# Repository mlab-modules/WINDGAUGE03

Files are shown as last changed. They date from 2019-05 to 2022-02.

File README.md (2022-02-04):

<!--- PrjInfo ---> <!--- Please remove this line after manually editing --->
<!--- 00a56be08b96043df9e37d6aff7b6990 --->
<!--- Created:2019-04-25 18:04:07.487886: ---> 
<!--- Author:: ---> 
<!--- AuthorEmail:: ---> 
<!--- Tags:: ---> 
<!--- Ust:: ---> 
<!--- Label --->
<!--- ELabel ---> 
<!--- Name:WINDGAUGE03A: --->
# WINDGAUGE03A
<!--- LongName --->
## Venturi tube based anemometer
<!--- ELongName ---> 

<!--- Lead --->
High-endurance venturi anemometer with minimum moving parts. Automatic estimation of direction to magnetic nort. 
<!--- ELead ---> 

<!--- Description --->

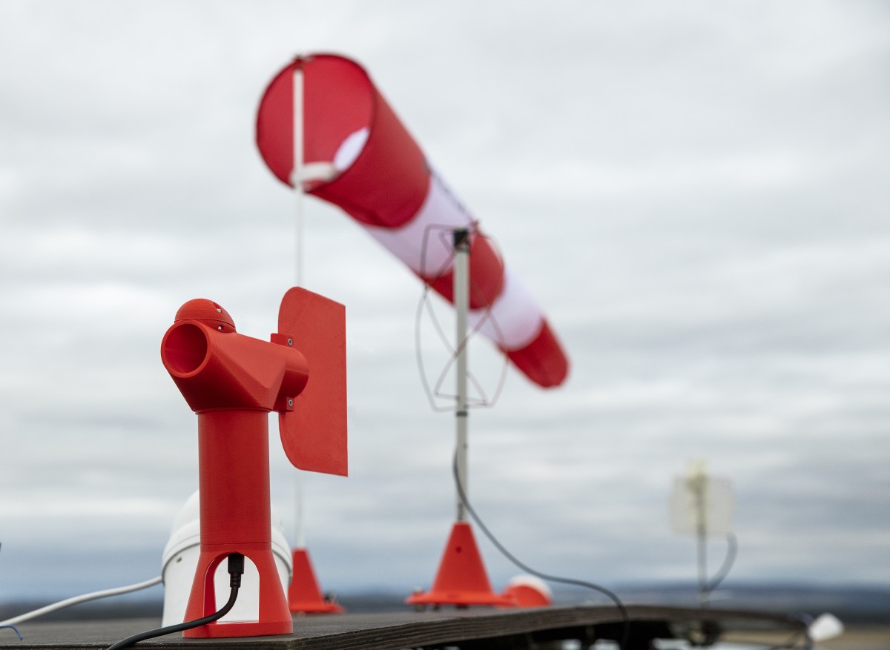
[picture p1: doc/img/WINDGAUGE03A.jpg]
WINDGAUGE03A
 

### Advantages
  * Minimised number of moving parts results in increased durability
  * Venturi effect allows accurate measurement in wide range of speeds is especially sensitive for common low airspeeds  

### Function principle

The measuring tube consist an orifice, which increases airflow in the tube. The different speeds generates differentiall preassure, which is measured by electronic differential pressure sensor.  The same principle was used in beginnig of [aircraft airspeed measurement](https://ntrs.nasa.gov/citations/19930091190). It is advantageous due to better sensitivity at lows speeds compared to [pitot-static](https://en.wikipedia.org/wiki/Pitot_tube) tube. 

The anemometer consists the IMU sensor ICM-20948 which contains magnetometer, gyroscopes and accelerometers. The IMU allows sophisticated data aquisition for failure detection and gust wind analysis. 

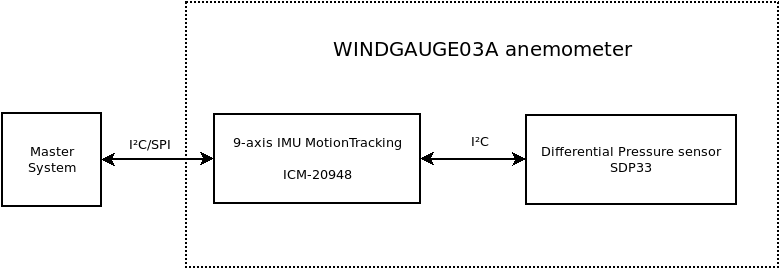
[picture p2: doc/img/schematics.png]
WINDGAUGE03A schematics
 

### Main parameters
  
  * Absolute azimuth accuracy 1° (to magnetic north)
  * Wind speed measurement range 0-120 km/h
  * Maximum mechanically safe wind speed 150 km/h
  * Communication interfaces: 
    * USB
    * I²C
  * Operational temperature range -20/+45 °C
  * Maximum hail diameter 0.5 cm 

### Software installation 

The anemometer uses [pymlab](https://github.com/MLAB-project/pymlab) software toolkit to interface with a station computer. The toolkit also contains an [example](https://github.com/MLAB-project/pymlab/blob/master/examples/windgauge03a_example.py) which allows basic calibration and data recording of anemometer data. 

#### Usage 

##### Calibration 

Anemometer should be calibrated before the first use. That ensures, calibration of magnetometer parameters. To correctly determine the wind direction by internal magnetometer. 

    python3 serial_logger.py 68  15

<!--- EDescription --->
<!--- Content --->
<!--- EContent --->
<sub><sup> Generated with [MLABweb](https://github.com/MLAB-project/MLABweb). (2019-04-25)</sup></sub>

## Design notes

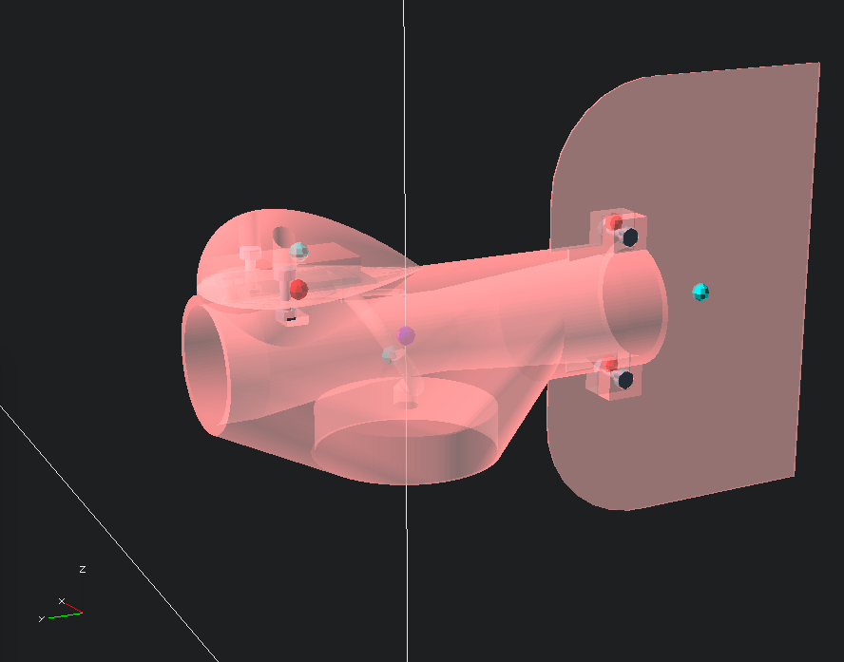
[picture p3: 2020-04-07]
doc/img/rotorpart_balancing.png

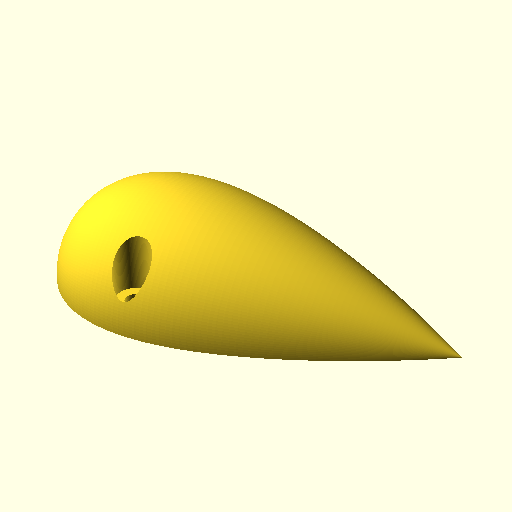
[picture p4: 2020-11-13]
doc/img/WINDGAUGE_R04.png

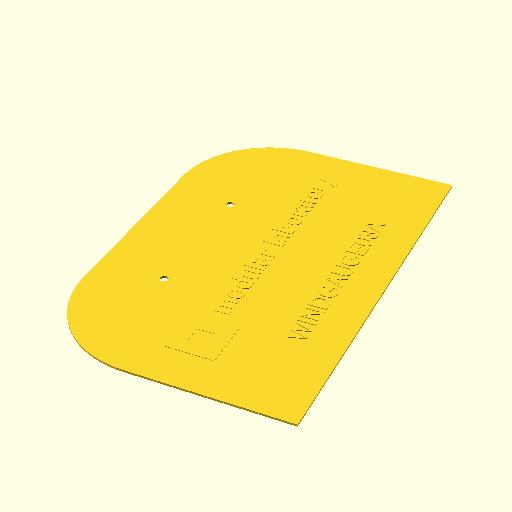
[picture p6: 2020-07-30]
doc/img/WINDGAUGE_R05.png

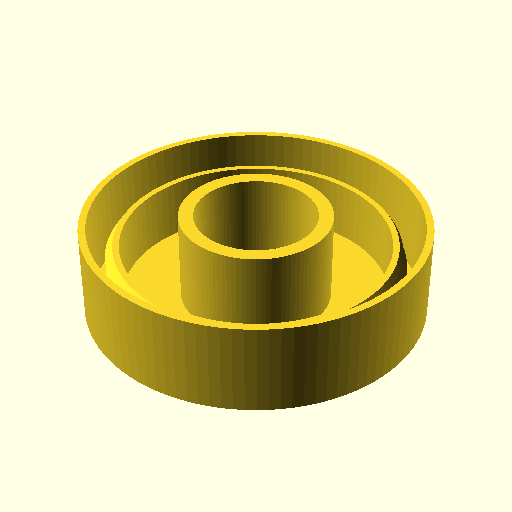
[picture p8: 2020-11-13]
doc/img/WINDGAUGE_S01.png

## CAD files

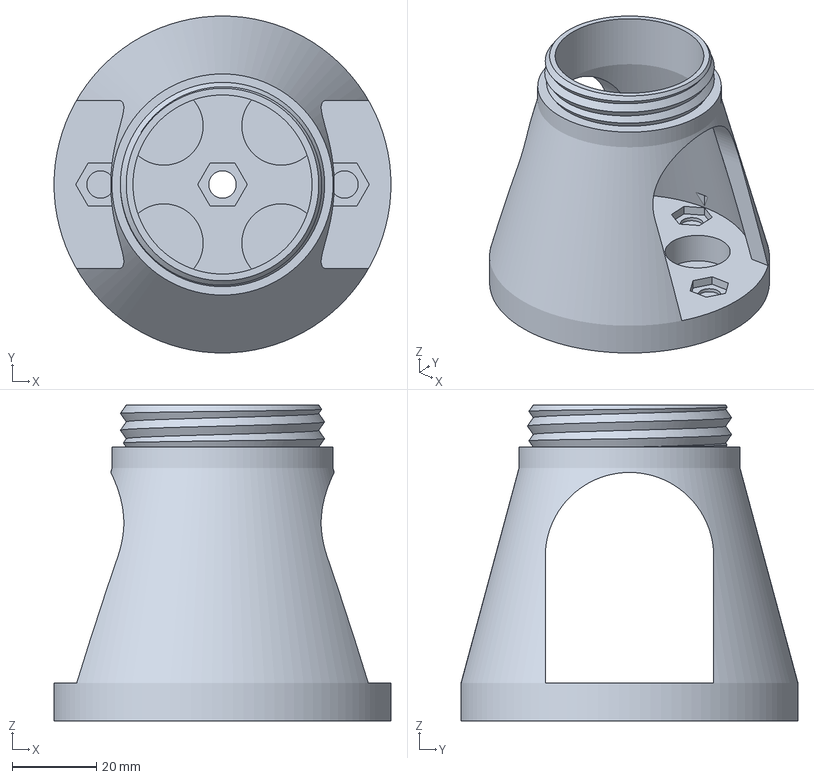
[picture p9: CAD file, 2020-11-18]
amf/WINDGAUGE_D02.amf
80.0 x 80.0 x 75.0 mm

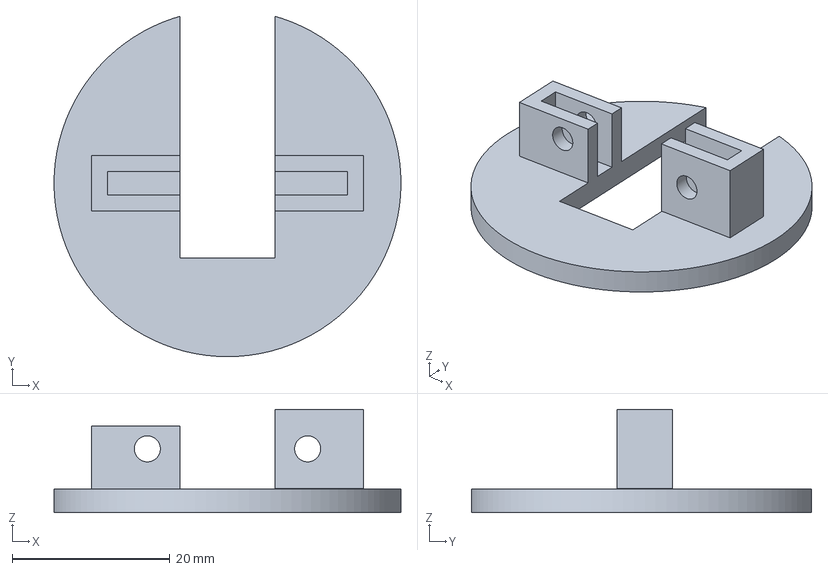
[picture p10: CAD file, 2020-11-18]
amf/WINDGAUGE_S04_USBI2C01A.amf
44.0 x 43.2 x 13.1 mm

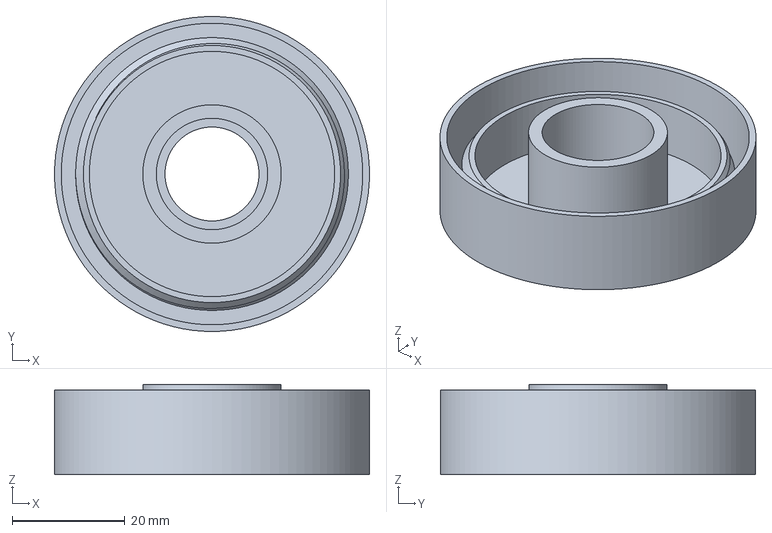
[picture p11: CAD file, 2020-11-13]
amf/WINDGAUGE_S01.amf
56.0 x 56.0 x 16.0 mm

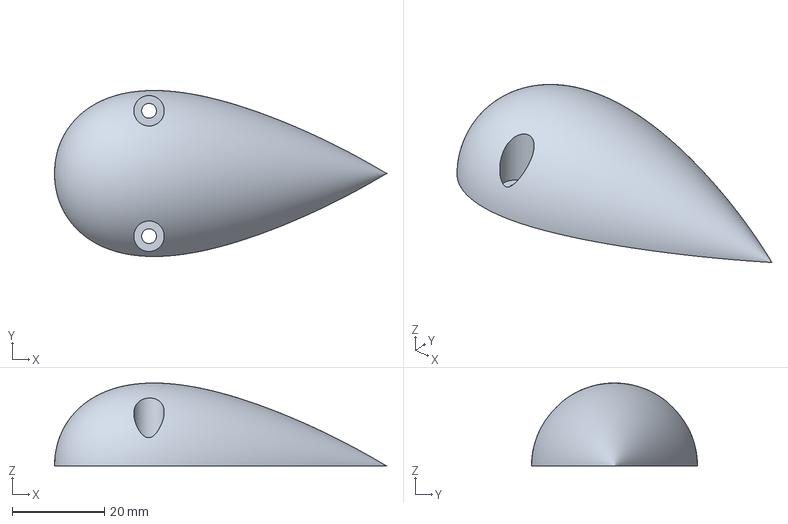
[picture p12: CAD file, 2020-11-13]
amf/WINDGAUGE_R04.amf
72.0 x 36.0 x 18.0 mm

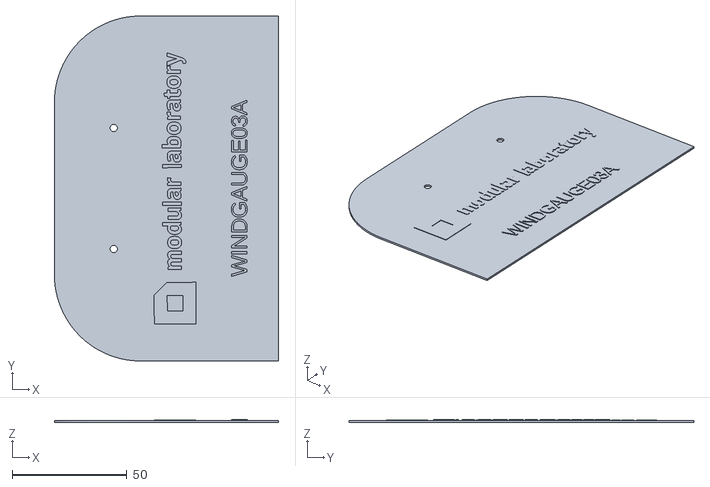
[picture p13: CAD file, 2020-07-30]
doc/stl/WINDGAUGE_R05.stl
97.5 x 150.0 x 1.10

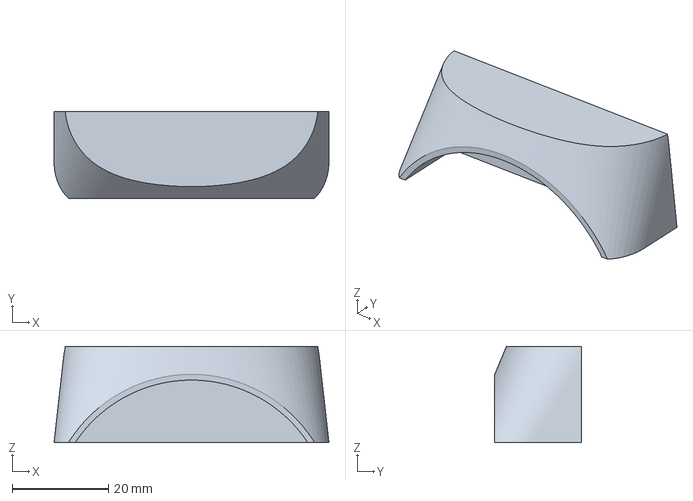
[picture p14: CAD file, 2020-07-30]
amf/WINDGAUGE_R03_test.amf
57.2 x 18.0 x 20.0 mm

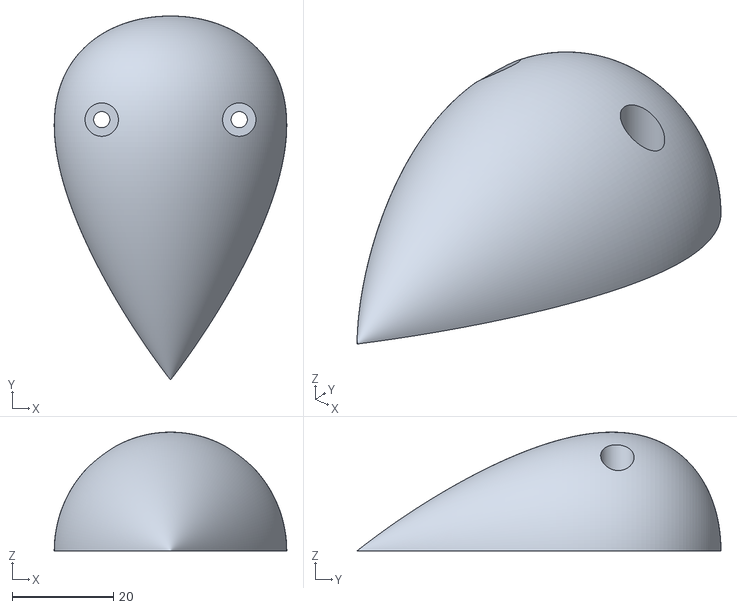
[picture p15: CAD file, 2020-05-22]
doc/stl/WINDGAUGE_R04.stl
46.0 x 72.0 x 23.5

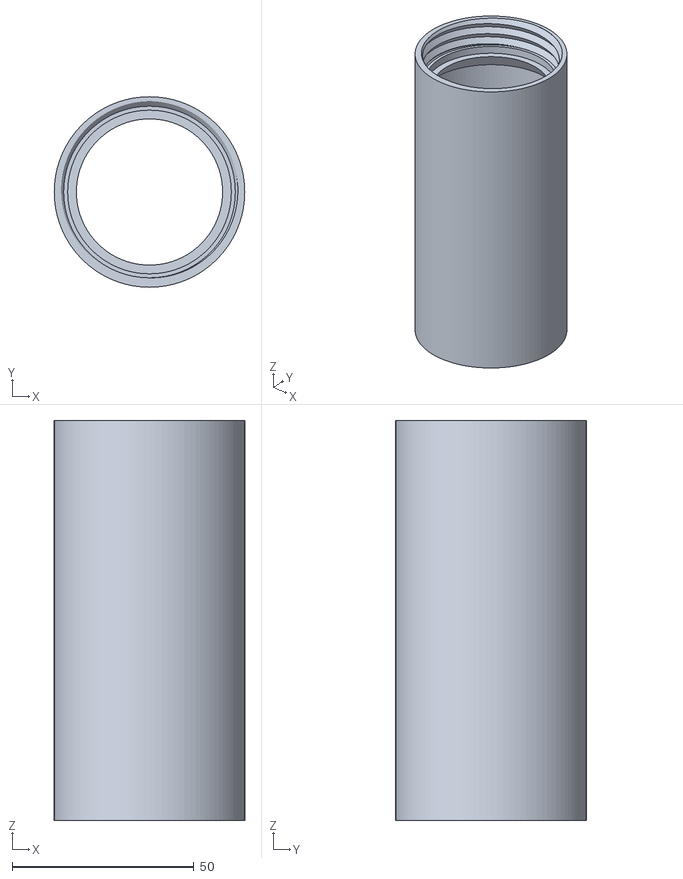
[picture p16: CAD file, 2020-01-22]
doc/stl/WINDGAUGE_S02.stl
52.4 x 52.4 x 110.0

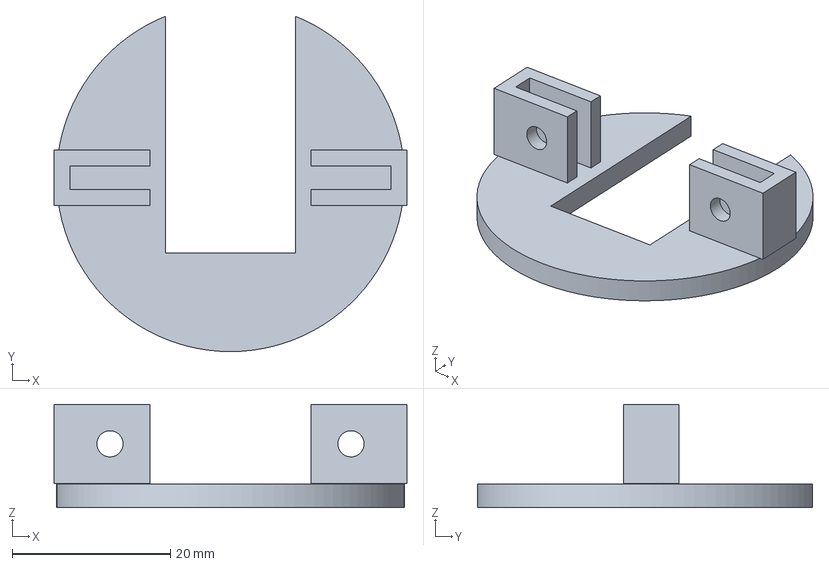
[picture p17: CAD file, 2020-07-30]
amf/WINDGAUGE_S04.amf
44.6 x 42.4 x 13.1 mm

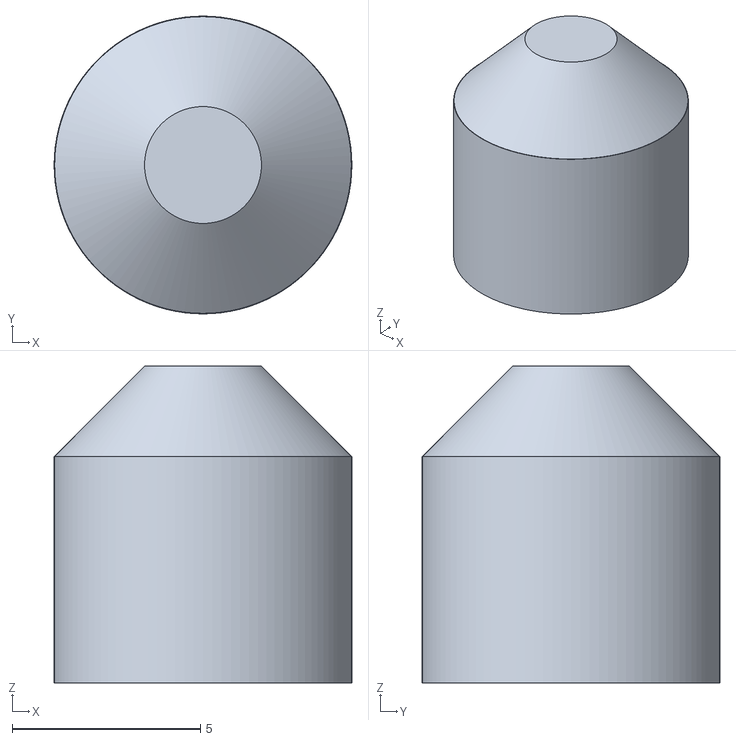
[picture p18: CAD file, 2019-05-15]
doc/stl/WINDGAUGE_R06.stl
7.90 x 7.90 x 8.41

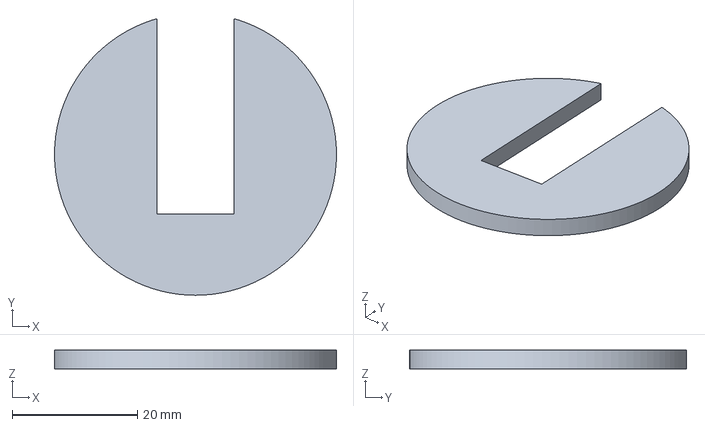
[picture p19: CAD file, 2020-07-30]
amf/WINDGAUGE_S03.amf
45.0 x 44.1 x 3.00 mm

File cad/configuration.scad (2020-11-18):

//$fn=40; // model faces resolution.

//COMMON PARAMETERS
global_clearance = 0.5; // additional space where needed due to printer precision
layer_thickness = 0.3; // layer which is going to be removed after printing
//M3 x 12 Bolt
M3_nut_diameter = 6.6;
M3_nut_height = 2.7;
M3_bolt_diameter = 3.2;
M3_bolt_head_height = 3;
M3_bolt_length = 12;
//M5 Bolt
M5_bolt_diameter = 5.5;
M5_nut_height = 4.5;
M5_nut_diameter = 9.4;
//M6 Bolt
M6_bolt_diameter = 6.5;
M6_nut_height = 4.9;
M6_nut_diameter = 11.8;


//----------------------------------------------------------------
//----------------------------------------------------------------
//WINDGAUGE02A_S02 - Parametry pro hlavni valec anemometru
S01_hloubka_zavitu=4;
S01_vyska=110; //80
S01_prumer_vnitrni=50;
S01_sila_materialu=1.2;
S01_vyska_horni_zavit=10;
S01_vyska_spodniho_zavitu=10;
S01_sila_drzaku_RJ11=3; //vyška drážky
S01_hrana_A_RJ11=12.3;
S01_hrana_B_RJ11=19;
S01_tolerance_zavit=1.5;

//Rozměry ložiska se závity
//LO_spodni_prumer=22;
LO_spodni_prumer=16.7; //bez krytu
slip_ring_mount_height=1.5;
slip_ring_mount_diameter=16.7;
LO_horni_prumer=7.7;
//LO_vyska_spodni_doraz=5;
//LO_vyska_horni_doraz=9;
//LO_vyska_dorazu=0;
slip_ring_body_height = 16;
slip_ring_body_diameter = 19.8;



//Obecné parametry
prumer_osicky=5.1;



//Parametry loziska
lozisko_prumer_vnitrni=4.9;
lozisko_prumer_vnejsi=16.1;
lozisko_vyska=5;
lozisko_prekryv=1.5;

//Parametry magnetu
magnet_prumer=6.3;
magnet_vyska=5;
magnet_zapusteni=2;
magnet_tolerance_prumeru=0.2;

//Parametry sroubu
prumer_sroubu=3.4;
prumer_hlavy_sroubu=8.2;
vyska_hlavy_sroubu=4.3;
vyska_matky=3;
sirka_matky=6.7;

sirka_matky_tol=0.175;
prumer_orechu=10;

//WINDGAUGE02A_R01 //pro lopatku
L01_hrana_drzaku_a=10;
L01_hrana_drzaku_b=3;
L01_delka_uchytu=19;
L01_prumer_lopatky=40;
L01_sila_materialu_lopatky=0.9;

//WINDGAUGE02A_D02 Anemometer holder
//   | |   Top ring with Screw-thread
//  /   \  Body
// |_____| Base
D02_magnet_base_height = 4.5 + 1.5*global_clearance; // HS-13 M5 magnet height without bolt
D02_magnet_diameter = 16.1 + global_clearance; // HS-13 M5 magnet diameter
D02_flat_magnet_diameter = 18.1 + global_clearance; // HS-13 M5 magnet diameter
D02_wall_thickness = 5; // body wall thickness
D02_connector_spacing = 40; // main body cut-through for connectors
D02_base_diameter = 80; // diameter of holder base
D02_base_height = max(M6_nut_height + 1.5,
                      D02_magnet_base_height + M5_nut_height/2 + 1.5); // height of holder base
D02_body_height = 60 - D02_base_height; // height of body between base and top ring
D02_screw_diameter = S01_prumer_vnitrni - S01_tolerance_zavit; // scew-thread diameter based on stand S01
D02_thread_height = S01_vyska_spodniho_zavitu; // screw-thread height based on stand S01
D02_top_ring_inner_diameter = D02_screw_diameter - 6; // inner diameter of top ring
D02_top_ring_outer_diameter = D02_screw_diameter + 4; // outer diameter of top ring
D02_top_ring_height = D02_thread_height + 5; // height of top ring
D02_total_height = D02_base_height + D02_body_height + D02_top_ring_height; // total height of anemometer holder
// Following parameters are obsolete, maintained only for compatibility.
D01_material_pod_zavitem = D02_top_ring_height - D02_thread_height;
D01_material_za_zavitem = D02_screw_diameter - D02_top_ring_inner_diameter;
D01_material_pred_zavitem = D02_top_ring_outer_diameter - D02_screw_diameter;
D01_polomer_zakladny = D02_base_diameter/2;
D01_sila_setny_spodniho_drzaku=D02_wall_thickness;
D01_vyska_spodni_casti_drzaku = D02_body_height + D02_base_height;
D01_sirka_otvoru_pro_konektor = D02_connector_spacing;
D01_ucyhtna_matice_material_nad = D02_base_height - M6_nut_height;
D01_uchytna_matice_vyska = M6_nut_height;
D01_uchytna_matice_sirka = M6_nut_diameter;
D01_uchytny_sroub_prumer = M6_bolt_diameter;

// Following parameters are actually used in D01 model.
//WINDGAUGE02A_D02 //uchyt na sloup
D02_sila_materialu=6;
D02_vyska_uchytky=40;
D02_prumer_obruby=27; // 3/4 trubka
D02_delka_celeho_uchytu=60;
D02_dotahova_vzdalenost=1.5;
D02_prumer_uchytneho_sroubu=4.2;
D02_sirka_matky=9.1; //pro M4
D02_vyska_matky=3;


//WINDGAUGE02A_R01 //rotor s prekritim statoru
R01_vyska_prekryti_statoru=10;
R01_sila_materialu_pro_prekriti=1.3;
R01_mezera_mezi_statorem_rotorem=3;

//WINDGAUGE02A_R03 //drzak magnetu
R05_sirka_matky=10;



R03_prumer_zavitu=40;
R04_zavit_vyska=5;
R02_zavit_vyska=10;
R01_zavit_vyska=5;
R03_mezera_mezi_statorem_rotorem=3;

R02_delka_kridla=45;
R02_vzdalenost_der=25;

R02_delka_vyrovnnavaci_tyce=35;
R02_hrana_drzaku=14;
R02_sila_materialu_pod_tyci=5;
R02_sila_materialu_kridla=1.2;
R02_sila_materialu_kridla_tolerance=0.3;

R05_vyska_kridla=100;
R05_delka_kridla=100;


//S04
I2CDIFF01A_sirka_kon=16.5; //sirka konektoru
I2CDIFF01A_vyska_kon=13.5; //vyska konektoru
I2CDIFF01A_sirka_mod_otvory=4; //kolik modul zabira der
I2CDIFF01A_vyska_PCB=2; //vyska mezi albase a konektorem
S04_sila_materialu=2;

//S04_USBI2C01A
USBI2C01A_sirka_kon=12; //sirka konektoru
USBI2C01A_vyska_kon=11; //vyska konektoru
USBI2C01A_sirka_mod_otvory=3; //kolik modul zabira der
USBI2C01A_vyska_PCB=2; //vyska mezi albase a konektorem


//WINDGAUGE03A_R03 // Venturi tube
R03_wide_D = 36; // Venturi wide tube inner diameter
R03_narrow_D = R03_wide_D/1.7; // Venturi narrow tube inner diameter
R03_global_clearance = global_clearance; // additional space where needed due to printer precision
R03_PCB_top_rim = 5.5; // vertical distance from top of tube to top of PCB
R03_PCB_height = 41; // height of PCB casing - if changed check casing
R03_PCB_width = 14; // width of PCB casing - if changed check casing
R03_PCB_depth = 3.7; // depth of PCB casing - if changed check casing
R03_PCB_connector_overlay = 2.5; // additional depth of PCB casing on connectors side - if changed check casing
R03_PCB_elevation = 2; // additional elevation of PCB for waterproofing
R03_air_tube_diameter = 2; // air tubes diameter
R03_sensor_housing_offset = 15;  // distance from venturi tube height to sensor housing drop
R03_sensor_offset = 2.2;  // SDP33 distance from PCB border to sensor
R03_sensor_pitch = 4.3;  // SDP33 distance between sensors
R03_sensor_diameter = 3.5;  // SDP33 sensor diameter
R03_sensor_depth = 2.5;  // SDP33 sensor depth
R03_slip_ring_offset = 0; // slip-ring offset from tube center
R03_venturi_tube_height = 150;  // Venturi tube height (limited by max print size)
R03_wall_thickness = 5; // Venturi tube wall thickness
R03_sealing_ring_thickness = 1.5; // sealing ring size
R03_fin_width = 0.8; // width of vertical stabilizator
R03_fin_length = 80; // length of vertical stabilizator
R03_fin_height = 150; // height of vertical stabilizator
R03_fin_holder_width = M3_bolt_length + M3_nut_height;
R03_fin_holder_height = M3_nut_diameter + 2*R03_wall_thickness;
R03_fin_holder_depth = R03_wide_D/2 + R03_fin_holder_height;
R03_balance_shelf_width = 20; // width of shelf for balance weights
R03_balance_shelf_height = 10; // height of shelf for balance weights

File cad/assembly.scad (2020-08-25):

include <configuration.scad>

parts_separation = 0;

//D02 - Anemometer holder
D02_z0 = 0;
translate([0, 0, D02_z0])
    rotate([0, 0, 0])
        import("../doc/stl/WINDGAUGE_D02.stl");

//S02 - Extender
S02_z0 = D02_z0 + D02_total_height - D02_thread_height + parts_separation;
translate([0, 0, S02_z0])
    rotate([0, 0, 0])
        import("../doc/stl/WINDGAUGE_S02.stl");

//S01 - Bearings holder
S01_z0 = S02_z0 + S01_vyska + parts_separation;
translate([0, 0, S01_z0])
    rotate([180, 0, 0])
        import("../doc/stl/WINDGAUGE_S01.stl");

//R03 - Venturi tube
R03_y0 = -2*R03_venturi_tube_height + R03_slip_ring_offset + 6*R03_wide_D;
R03_z0 = S01_z0 + R03_wide_D/2 + 5 + parts_separation;
%translate([0, R03_y0, R03_z0])
    rotate([270, 180, 0]){
        import("../doc/stl/WINDGAUGE_R03.stl");
    }
echo("WINDGAUGE_R03 coordinates are: [0, ", R03_y0, R03_z0, "]");

//R04 - PCB lid
R04_x0 = -R03_wide_D/2;
R04_y0 = R03_venturi_tube_height + R03_y0;
R04_z0 = R03_z0 + R03_wide_D/2 + R03_wall_thickness + parts_separation;
%translate([R04_x0, R04_y0, R04_z0 + 0])
    rotate([0, 0, 270])
        import("../amf/WINDGAUGE_R04.amf");
echo("WINDGAUGE_R04 coordinates are: [", R04_x0, R04_y0, R04_z0, "]");


//R05 - Fin
R05_y0 = - 2*R03_venturi_tube_height + R03_slip_ring_offset + 6*R03_wide_D
         - R03_fin_length/2 + R03_fin_holder_height - parts_separation;
R05_z0 = R03_z0;
%translate([0, R05_y0, R05_z0])
    rotate([90, 0, 270])
        import("../amf/WINDGAUGE_R05.amf");
echo("WINDGAUGE_R05 coordinates are: [0, ", R05_y0, R05_z0, "]");

// R03 Front Bolt
FTB_x0 = -M3_bolt_length/2 - M3_nut_height/2;
FTB_y0 = 6.5;
FTB_z0 = R03_z0 - R03_wide_D/2;
color([1, 1, 1])
translate([FTB_x0, FTB_y0, FTB_z0])
    rotate([0, 90, 0])
        import("../amf/BOLT_M3x12.amf");
echo("R03 Front Bolt coordinates are: [",FTB_x0, FTB_y0, FTB_z0,"]");

// R03 Rear Bolt
RTB_x0 = M3_bolt_length/2 + M3_nut_height/2;
RTB_y0 = -6.5;
RTB_z0 = R03_z0 - R03_wide_D/2;
color([1, 1, 1])
translate([RTB_x0, RTB_y0, RTB_z0])
    rotate([0, 90, 180])
        import("../amf/BOLT_M3x12.amf");
echo("R03 Rear Bolt coordinates are: [",RTB_x0, RTB_y0, RTB_z0,"]");

// R04 Left Bolt
LLB_x0 = -R03_PCB_width/2 - M3_nut_diameter;
LLB_y0 = R03_y0 + R03_venturi_tube_height - R03_PCB_height/2;
LLB_z0 = R03_z0 + R03_wide_D/2 - M3_nut_height;
color([1, 1, 1])
translate([LLB_x0, LLB_y0, LLB_z0])
    rotate([0, 0, 90])
        import("../amf/BOLT_M3x12.amf");
echo("R04 Left Bolt coordinates are: [",LLB_x0, LLB_y0, LLB_z0,"]");

// R04 Right Bolt
RLB_x0 = R03_PCB_width/2 + M3_nut_diameter;
RLB_y0 = R03_y0 + R03_venturi_tube_height - R03_PCB_height/2;
RLB_z0 = R03_z0 + R03_wide_D/2 - M3_nut_height;
color([1, 1, 1])
translate([RLB_x0, RLB_y0, RLB_z0])
    rotate([0, 0, 90])
        import("../amf/BOLT_M3x12.amf");
echo("R04 Right Bolt coordinates are: [",RLB_x0, RLB_y0, RLB_z0,"]");

// R05 Upper Bolt
UFB_x0 = -R03_fin_holder_width/2;
UFB_y0 = R03_y0 + R03_fin_holder_height/2;
UFB_z0 = R03_z0 + R03_fin_holder_depth - R03_fin_holder_height/2;
color([1, 1, 1])
translate([UFB_x0, UFB_y0, UFB_z0])
    rotate([0, 90, 0])
        import("../amf/BOLT_M3x12.amf");
echo("R05 Upper Bolt coordinates are: [",UFB_x0, UFB_y0, UFB_z0,"]");

// R05 Lower Bolt
LFB_x0 = -R03_fin_holder_width/2;
LFB_y0 = R03_y0 + R03_fin_holder_height/2;
LFB_z0 = R03_z0 - R03_fin_holder_depth + R03_fin_holder_height/2;
color([1, 1, 1])
translate([LFB_x0, LFB_y0, LFB_z0])
    rotate([0, 90, 0])
        import("../amf/BOLT_M3x12.amf");
echo("R05 Lower Bolt coordinates are: [",LFB_x0, LFB_y0, LFB_z0,"]");

// R03 COG
translate([ -0.4670859999999942 , 6.640354000000002 , 192.837544 ])
    color([0, 1, 1]) sphere(3);
// R04 COG
translate([ 1.0312389999999922 , 36.146445 , 228.245272 ])
    color([0, 1, 1]) sphere(3);
// R05 COG
translate([ -0.4690809999999989 , -101.44978800000001 , 197.63449400000002 ])
    color([0, 1, 1]) sphere(3);
// R03 Front Bolt COG
translate([ 0.7782590000000003 , 6.506229000000005 , 179.993901 ])
    color([1, 0, 0]) sphere(3);
// R03 Rear Bolt COG
translate([ -0.7782590000000003 , -6.506229000000004 , 179.993901 ])
    color([1, 0, 0]) sphere(3);
// R04 Left Bolt COG
translate([ -13.606229000000004 , 45.506099000000006 , 221.42825900000003 ])
    color([1, 0, 0]) sphere(3);
// R04 Right Bolt COG
translate([ 13.593770999999995 , 45.506099000000006 , 221.42825900000003 ])
    color([1, 0, 0]) sphere(3);
// R05 Upper Bolt COG
translate([ 0.7782590000000003 , -75.693771 , 224.293901 ])
    color([1, 0, 0]) sphere(3);
// R05 Lower Bolt COG
translate([ 0.7782590000000003 , -75.693771 , 171.69390099999998 ])
    color([1, 0, 0]) sphere(3);

// WINDGAUGE03_R* COG
translate([ -0.351634926309725 , 0.0062762700057576596 , 195.56655708002305 ])
    color([0, 0, 1]) sphere(3);

// // Desired WINDGAUGE03_R* COG
// translate([ 0, 0, R03_z0 ])
//     color([1, 0, 1]) sphere(3);

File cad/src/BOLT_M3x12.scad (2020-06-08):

include <../configuration.scad>
$fn=200;

cylinder(h = M3_bolt_length, d = M3_bolt_diameter, $fn=50);
cylinder(h = M3_nut_height, d = M3_nut_diameter, $fn=6);
translate([0, 0, M3_bolt_length])
    cylinder(h = M3_bolt_head_height, d = M3_nut_diameter);

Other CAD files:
doc/stl/WINDGAUGE_D02.stl
doc/stl/WINDGAUGE_S04_USBI2C01A.stl
doc/stl/WINDGAUGE_S01.stl
amf/WINDGAUGE_R05.amf
doc/stl/WINDGAUGE_S04.stl
amf/WINDGAUGE_S02.amf
doc/stl/WINDGAUGE_S03.stl
cad/src/WINDGAUGE_R03.scad
amf/BOLT_M3x12.amf
amf/P_WINDGAUGE03A_R03.stl
amf/WINDGAUGE_R03.amf
amf/WINDGAUGE_R03.stl
amf/WINDGAUGE_R06.amf
cad/print_data/P_WINDGAUGE01A_D02.scad
cad/print_data/P_WINDGAUGE01A_R01.scad
cad/print_data/P_WINDGAUGE01A_R03.scad
cad/print_data/P_WINDGAUGE01A_R04.scad
cad/print_data/P_WINDGAUGE01A_S01.scad
cad/print_data/P_WINDGAUGE01A_S02.scad
cad/print_data/P_WINDGAUGE01A_S04.scad
cad/src/WINDGAUGE_D02.scad
cad/src/WINDGAUGE_R04.scad
cad/src/WINDGAUGE_R05.scad
cad/src/WINDGAUGE_R06.scad
cad/src/WINDGAUGE_S01.scad
cad/src/WINDGAUGE_S02.scad
cad/src/WINDGAUGE_S03.scad
cad/src/WINDGAUGE_S04.scad
cad/src/WINDGAUGE_S04_USBI2C01A.scad
doc/stl/BOLT_M3x12.stl

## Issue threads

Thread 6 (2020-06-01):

Uložení servisní délky vodičů

kaklik, 2020-06-01:
Aktuálně navržené řešení uložení vodičů omotáním okolo PCB je prakticky nerealizovatelné.  Problémem je, že nelze udržet vodiče správně umístěné pod víčkem při nasazování víčka.

Nově navržený kanálek pro přivedení vodičů je však dostatečně tlustý na to, aby jím bylo možné protáhnout vodiče i s nakrimpovanými kontakty konektoru. Tím je umožněno zcela nové řešení, že by vodiče byly rovnou správně dlouhé a mohly být přivedeny rovnou do konektoru.
Délka vodičů ale nikdy přesně správná nebude, pouze přibližně. Takže zde je potřeba mít nějakou co největší rezervu. Aktuálně jsem však vyzkoušel, že kanálek je tak široký že v něm vzniká asi 15mm rezerva délky, kterou do něj lze natlačit.  (Možná by bylo možné tuto rezervu zvětšit)

Případně by bylo možná udělat místo pro vodiče vytvořením druhého kanálku z protější strany, než kde vede teď. (Tento kanálek by asi mohl být slepý a přebytečná délka vodiče se do něj natlačí od PCB z vrchní strany)

Vyplývá z toho ale že je zřejmě potřeba obnovit původní menší kapkovitý kryt bez kulatých rohů. Ten byl lepší neboť nespotřebovával tolik materiálu a neměl takový aerodynamický odpor.

JanKott, 2020-06-10:
Zrušil jsem uložení vodiče pod víčko a přidal jsem více místa u vstupu do kanálku pro kabely.
Prosím otestovat, zda je to takto vyhovující.

kaklik, 2020-06-11:
Vodiče lze ukládat do nového tlustého kanálku, který vodiči přivádí.

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

Closed 2020-06-11.

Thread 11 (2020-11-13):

Uchycení modulu USBI2C

kaklik, 2020-11-13:
Do držáku není možné zašroubovat oba šrouby.

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

kaklik, 2020-11-18:
Supr! :)  Commit i obsahuje spojení s tímhle issue! :)

Zkusím to vytisknout a uvidíme, zda to zafungovalo.

kaklik, 2020-11-22:
Vypadá to tak všelijak... Ale účel to zřejmě splňuje..

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

Closed 2020-11-22.

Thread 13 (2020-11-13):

Tolerance trnu pro nasazení na ložisko

kaklik, 2020-11-13:
Jednotlivé typy ložisek mají mírně jiné průměry trnu. V důsledku toho současný průměr otvoru v otočném dílu nepasuje na Adafruit slip ring 22mm.

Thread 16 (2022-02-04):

Návod na sestavení

kaklik, 2022-02-04:
Šrouby pro fixaci osy mají délku 15mm.

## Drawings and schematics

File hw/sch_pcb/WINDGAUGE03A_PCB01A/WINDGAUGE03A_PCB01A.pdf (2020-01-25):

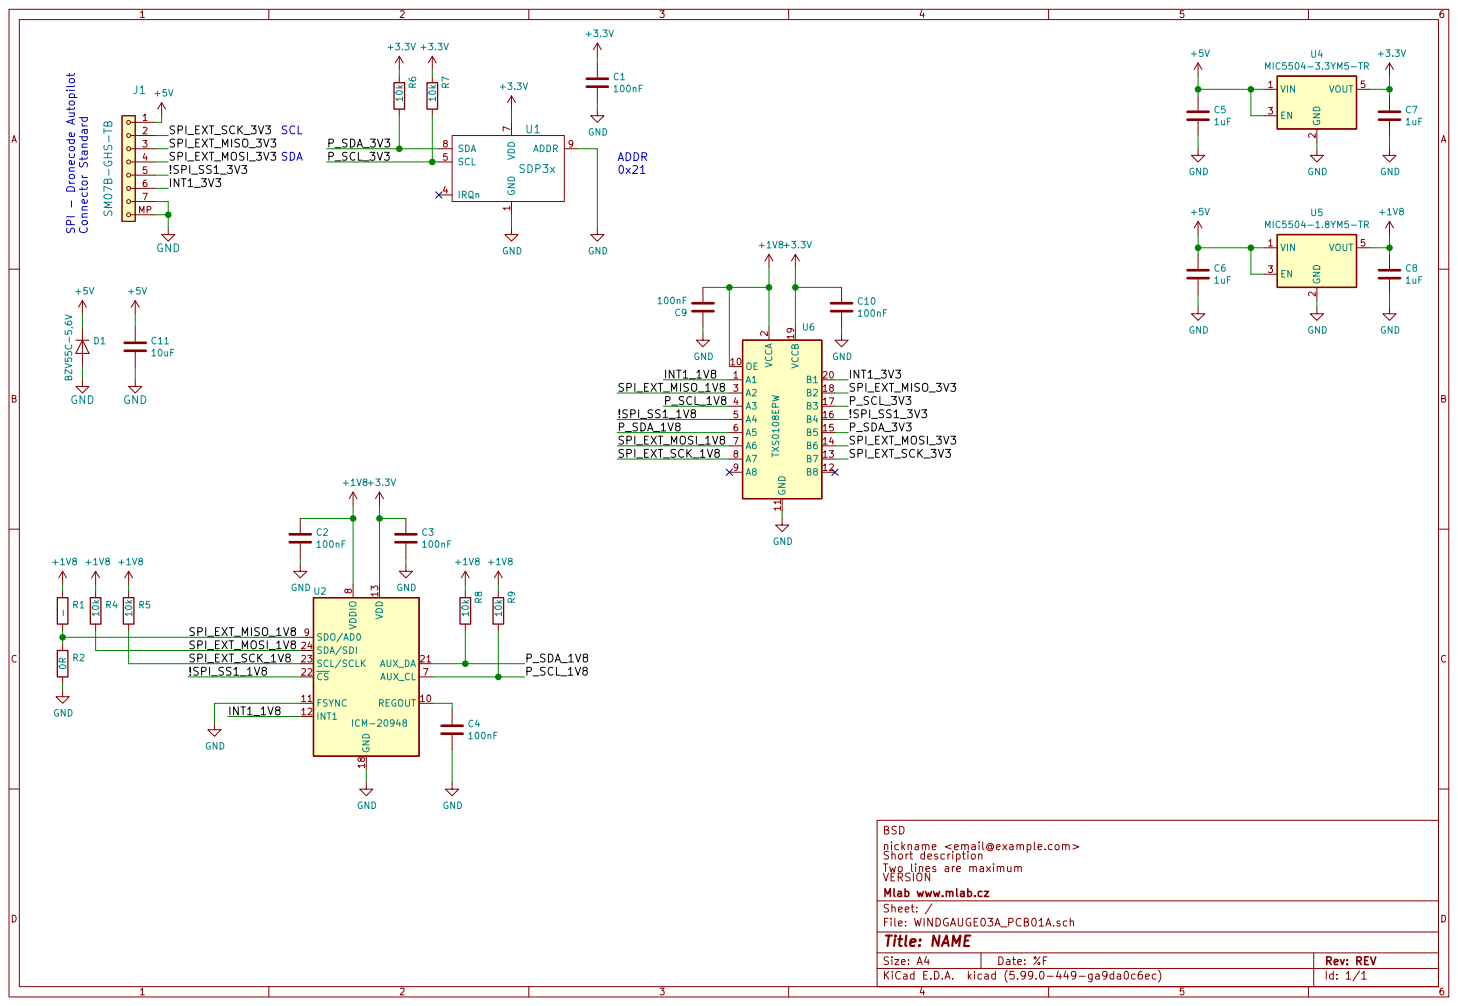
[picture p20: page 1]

+5V SPI - Dronecode Autopilot Connector Standard

7 SDA 8 ADDR 9 U1 SDP3x GND GND

nickname <email@example.com> BSD GND

Short description
File: WINDGAUGE03A_PCB01A.sch Sheet: / Mlab www.mlab.cz VERSION

Two lines are maximum

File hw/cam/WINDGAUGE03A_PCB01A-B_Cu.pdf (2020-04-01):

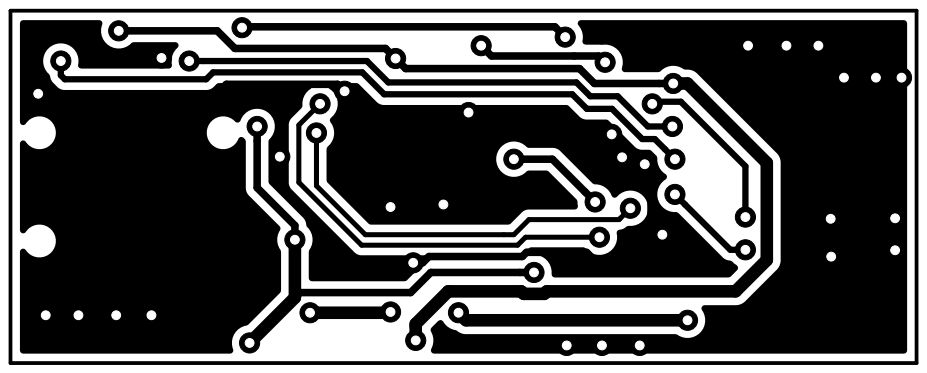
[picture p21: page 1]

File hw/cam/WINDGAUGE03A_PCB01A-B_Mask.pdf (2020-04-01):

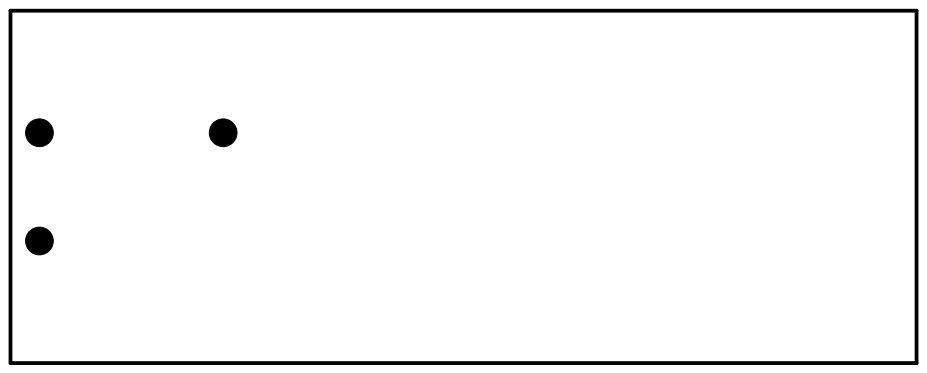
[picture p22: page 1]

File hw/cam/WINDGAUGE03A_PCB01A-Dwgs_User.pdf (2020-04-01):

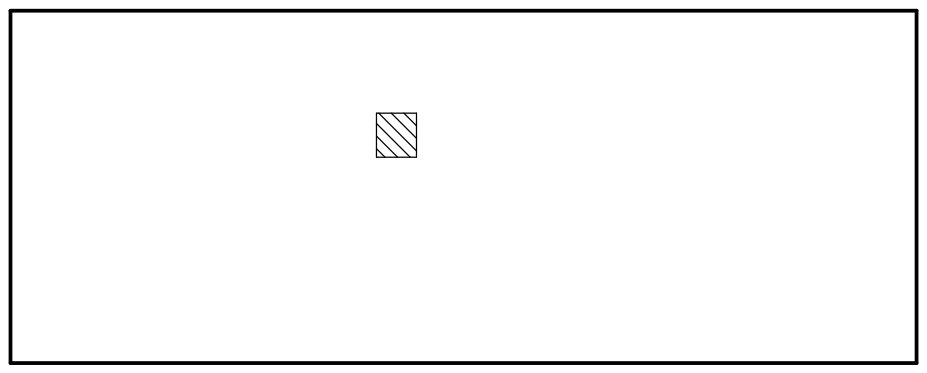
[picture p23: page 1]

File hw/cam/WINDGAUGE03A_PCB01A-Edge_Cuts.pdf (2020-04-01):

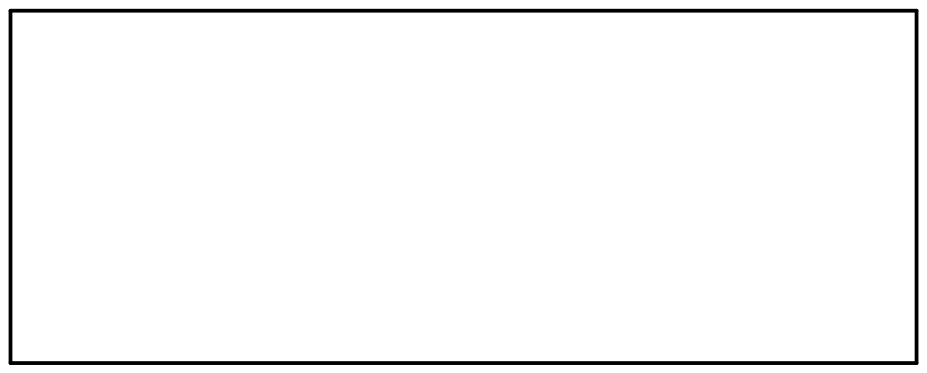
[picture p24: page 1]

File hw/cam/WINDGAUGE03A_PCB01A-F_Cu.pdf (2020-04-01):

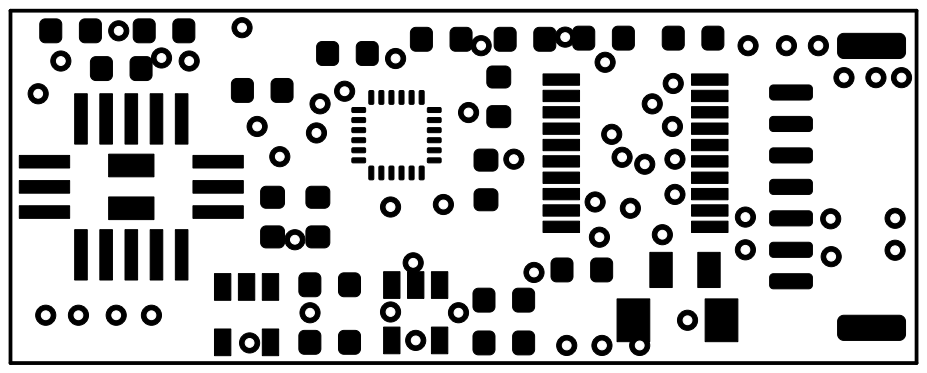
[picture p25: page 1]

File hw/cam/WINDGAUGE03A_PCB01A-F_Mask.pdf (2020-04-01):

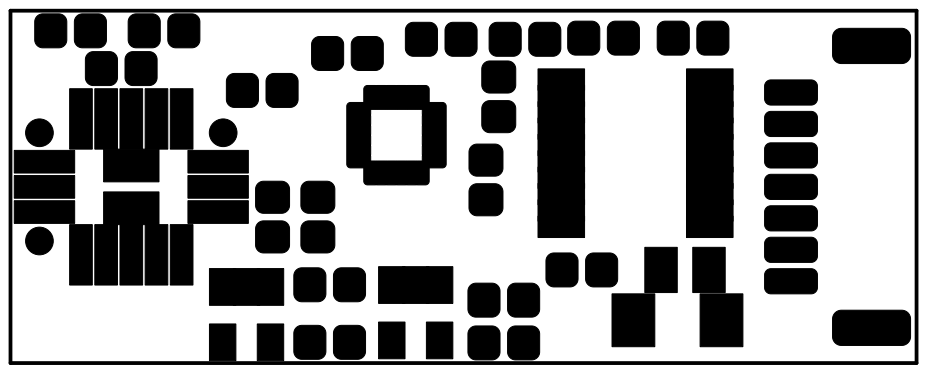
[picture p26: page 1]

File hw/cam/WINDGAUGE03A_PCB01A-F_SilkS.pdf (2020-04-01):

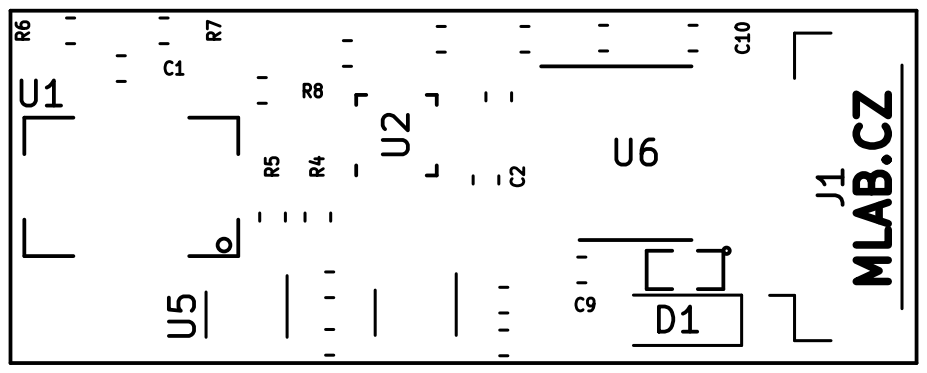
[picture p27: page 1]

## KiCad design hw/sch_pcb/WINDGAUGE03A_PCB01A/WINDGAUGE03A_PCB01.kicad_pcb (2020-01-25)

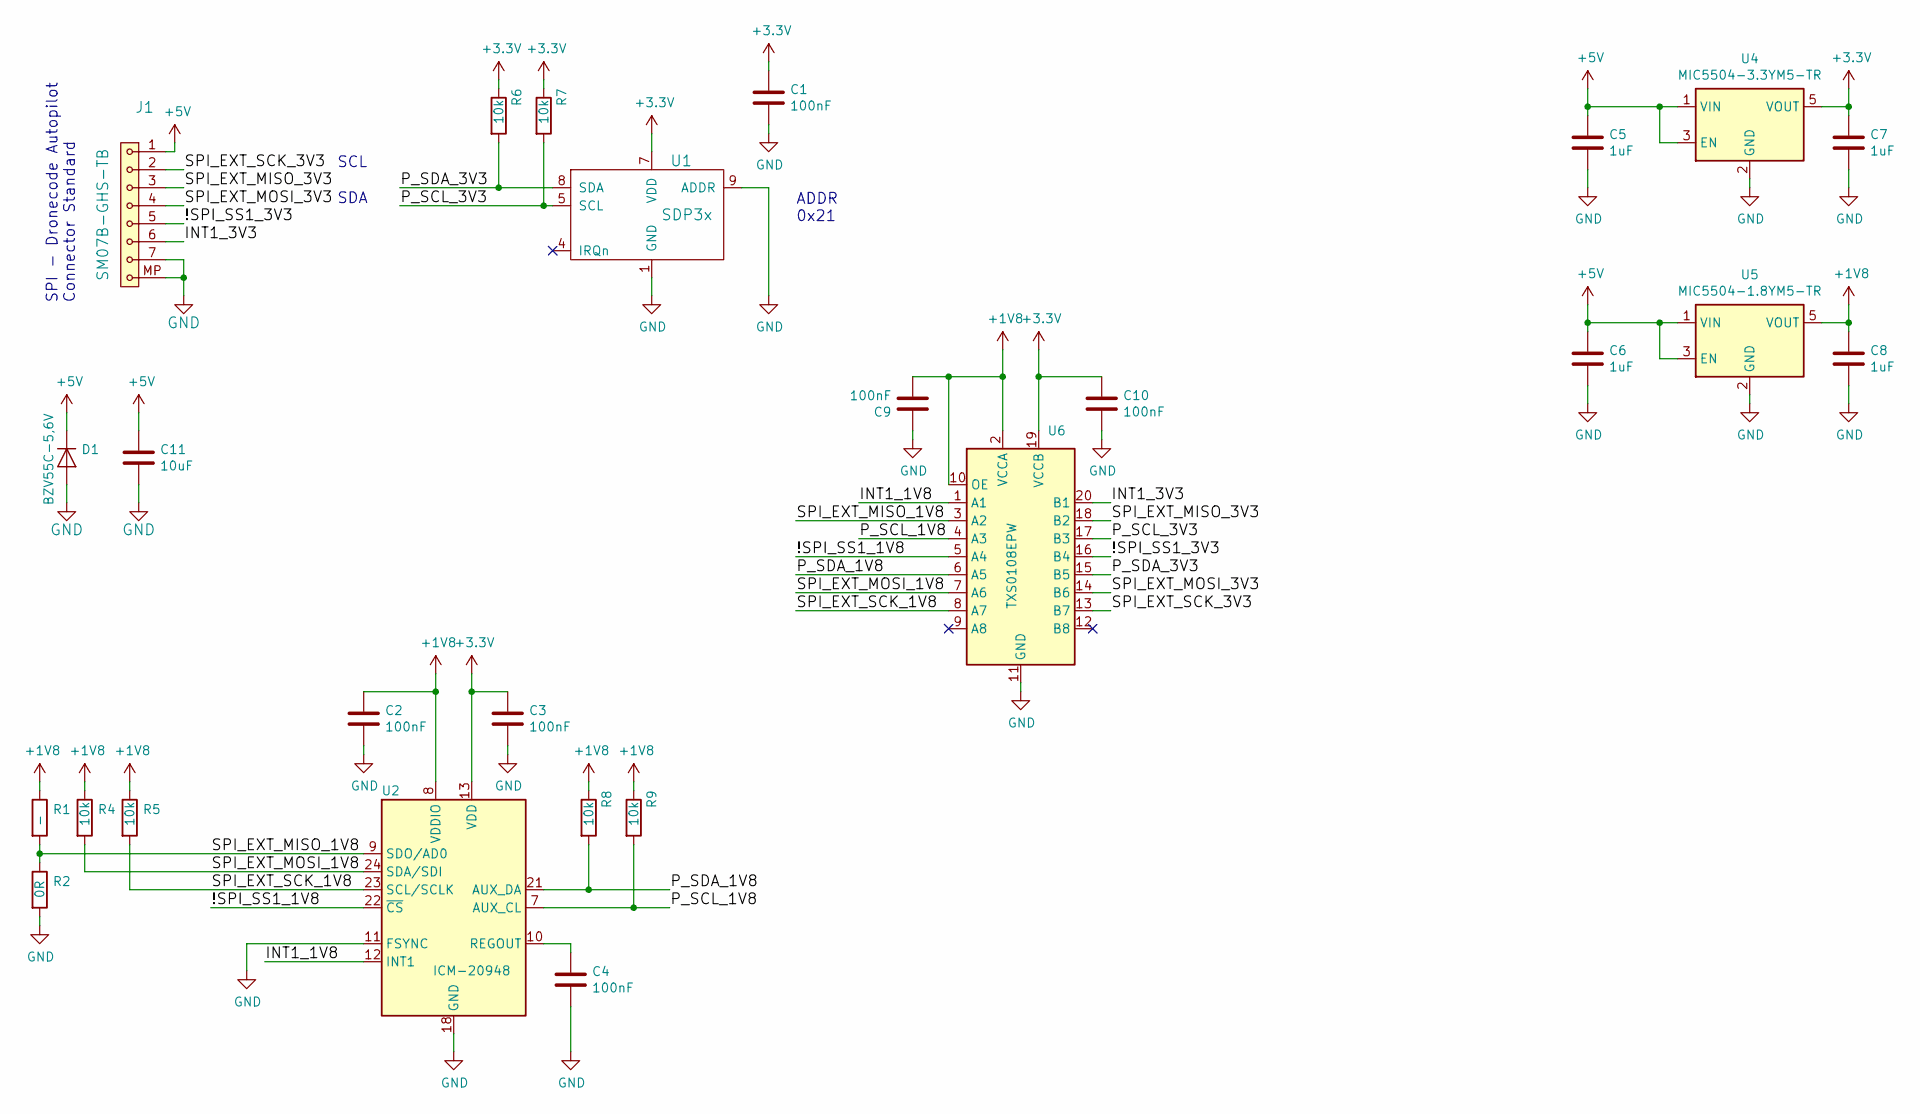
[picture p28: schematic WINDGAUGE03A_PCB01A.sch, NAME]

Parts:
C1, C2, C3, C4, C9, C10: 100nF; SMD-0603
C5, C6, C7, C8: 1uF; SMD-0603
C11: 10uF; SMD-0805
D1: BZV55C-5,6V; D_MiniMELF
J1: SM07B-GHS-TB; JST_GH_SM07B-GHS-TB_1x07-1MP_P1.25mm_Horizontal
R1: -; SMD-0603
R2: 0R; SMD-0603
R4, R5, R6, R7, R8, R9: 10k; SMD-0603
U1: SDP3x
U2: ICM-20948; InvenSense_QFN-24_3x3mm_P0.4mm
U4: MIC5504-3.3YM5-TR; SOT-23-5
U5: MIC5504-1.8YM5-TR; SOT-23-5
U6: TXS0108EPW; TSSOP-20_4.4x6.5mm_P0.65mm

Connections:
+1V8: C2.1, C8.1, C9.2, R1.1, R4.1, R5.1, R8.1, R9.1, U2.8 (VDDIO), U5.5 (VOUT), U6.2 (VCCA), U6.10 (OE)
+3V3: C1.1, C3.1, C7.1, C10.1, R6.1, R7.1, U1.7 (VDD), U2.13 (VDD), U4.5 (VOUT), U6.19 (VCCB)
+5V: C5.1, C6.1, C11.1, D1.1 (K), J1.1, U4.1 (VIN), U4.3 (EN), U5.1 (VIN), U5.3 (EN)
/!SPI_SS1_1V8: U2.22 (~CS), U6.5 (A4)
/!SPI_SS1_3V3: J1.5, U6.16 (B4)
/INT1_1V8: U2.12 (INT1), U6.1 (A1)
/INT1_3V3: J1.6, U6.20 (B1)
/P_SCL_1V8: R9.2, U2.7 (AUX_CL), U6.4 (A3)
/P_SCL_3V3: R7.2, U1.5 (SCL), U6.17 (B3)
/P_SDA_1V8: R8.2, U2.21 (AUX_DA), U6.6 (A5)
/P_SDA_3V3: R6.2, U1.8 (SDA), U6.15 (B5)
/SPI_EXT_MISO_1V8: R1.2, R2.1, U2.9 (SDO/AD0), U6.3 (A2)
/SPI_EXT_MISO_3V3: J1.3, U6.18 (B2)
/SPI_EXT_MOSI_1V8: R4.2, U2.24 (SDA/SDI), U6.7 (A6)
/SPI_EXT_MOSI_3V3: J1.4, U6.14 (B6)
/SPI_EXT_SCK_1V8: R5.2, U2.23 (SCL/SCLK), U6.8 (A7)
/SPI_EXT_SCK_3V3: J1.2, U6.13 (B7)
GND: C1.2, C2.2, C3.2, C4.2, C5.2, C6.2, C7.2, C8.2, C9.1, C10.2, C11.2, D1.2 (A), J1.7, J1.MP, R2.2, U1.1 (GND), U1.2 (GND), U1.3 (GND), U1.6 (GND), U1.9 (ADDR), U1.10 (GND), U1.11 (GND), U1.17 (GND), U1.18 (GND), U2.11 (FSYNC), U2.18 (GND), U2.20 (GND), U4.2 (GND), U5.2 (GND), U6.11 (GND)
unnamed: C4.1, U2.10 (REGOUT)

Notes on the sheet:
SPI - Dronecode Autopilot Connector Standard
ADDR 0x21
SDA
SCL

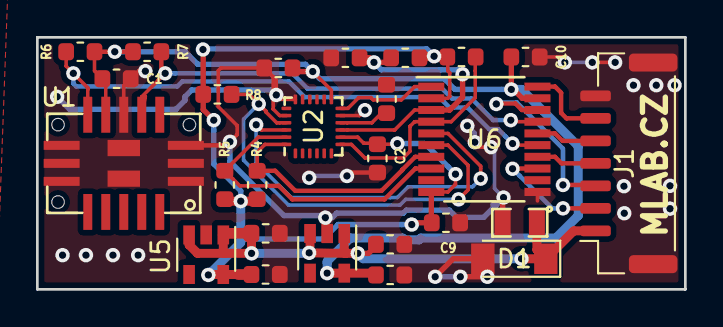
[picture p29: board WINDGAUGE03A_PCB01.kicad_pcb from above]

Board: 2 copper layers, 36.0 x 14.0 mm, 26 parts (0 on the bottom side), 19 nets.

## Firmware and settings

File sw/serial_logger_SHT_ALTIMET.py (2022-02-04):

from pymlab import config
import time
import sys
import math
import datetime
import os

#uncomment for debbug purposes
#import logging
#logging.basicConfig(level=logging.DEBUG)

#### Script Arguments ###############################################

if len(sys.argv) not in (2, 3, 4):
    sys.stderr.write("Invalid number of arguments.\n")
    sys.stderr.write("Usage: %s #I2CPORT [NMEA source] [cal=seconds] \n" % (sys.argv[0], ))
    sys.exit(1)

port = eval(sys.argv[1])

if len(sys.argv) == 3:
    import pynmea2
    import serial
    gps_port = str(sys.argv[2])
    serialPort = serial.Serial(gps_port, baudrate = 9600, timeout = 0.5)
else:
    serialPort = None

if len(sys.argv) > 3:
    if(str(sys.argv[2] == "cal")):
        cal = eval(sys.argv[3])
else:
    cal = 0
# select coniguration from config array bellow
#cfg_number = 1 # HIDAPI interface
cfg_number = 1 # SMBbus interface (needs kernel support)


cfglist=[
    config.Config(
        i2c = {
            "port": port,
            "device": "smbus",
        },
        bus = [
            {
                "name":        "windgauge",
                "type":        "WINDGAUGE03A",
            },
        ],
    ),
    config.Config(
        i2c = {
            "port": port,
            "device": "hid",
        },
        bus = [
            {
                "name":        "windgauge",
                "type":        "WINDGAUGE03A",
            },
            {
                "name":          "sht",
                "type":        "sht31",
                "address":        0x45,
            },
            {
                "name":          "altimet",
                "type":        "altimet01",
            },
        ],
    ),
]

try:
    cfg = cfglist[cfg_number]
except IndexError:
    sys.stdout.write("Invalid configuration number.\n")
    sys.exit(1)

cfg.initialize()
altimet = cfg.get_device("altimet")
time.sleep(0.5)

sht = cfg.get_device("sht")
sht.soft_reset()
time.sleep(0.1)


windgauge = cfg.get_device("windgauge")
windgauge.reset()
windgauge.initialize()
time.sleep(0.1)

if cal > 0:
    windgauge.calib_mag(cal)

def parseGPS(str):  # function for parsing and obtaining timestamp, heading and speed over ground data from gps receiver messages
    if str.find('VTG') > 0:
        msg2 = pynmea2.parse(str)
        print("Heading w.r.t. true north: %s -- Speed over ground [kmph]: %s", msg2.true_track, msg2.spd_over_grnd_kmph)

    # if str.find('GGA') > 0:
    #     msg = pynmea2.parse(str)
    #     print "Timestamp: %s -- Lat: %s %s -- Lon: %s %s -- Altitude: %s %s -- Satellites: %s" % (msg.timestamp,msg.lat,msg.lat_dir,msg.lon,msg.lon_dir,msg.altitude,msg.altitude_units,msg.num_sats)
    return(msg.timestamp, msg2.true_track, msg.spd_over_grnd_kmph)

def heading_ma(new_hdg, hdg_vect, ma_len, prev_hdg_ma): # function for smoothing heading values with moving average filter

    if new_hdg + 180 < prev_hdg_ma:
            new_hdg += 360
    if new_hdg - 180 > prev_hdg_ma:
        new_hdg -= 360

    prev_hdg_ma = new_hdg
    hdg_vect.append(new_hdg)
    hdg_ma = float(sum(hdg_vect)) / max(len(hdg_vect), 1)
    hdg_ma = hdg_ma % 360

    if hdg_ma < 0:
        hdg_ma += 360

    if len(hdg_vect) == ma_len:
        hdg_vect.pop(0)

    return(hdg_ma, hdg_vect, prev_hdg_ma)


hdg_vect = []
ma_len = 15   # length of moving average window filter
prev_hdg_ma = 0

error = False

#### Data Logging ###################################################
home =  os.path.expanduser("~")
path = home + "/WINDGAUGE03A_logs/"
try:
    os.makedirs(path)
except OSError:
    print("")
else:
    print ("Successfully created the directory %s\n" % path)

log_name = ("WINDGAUGE03A_log_%s.csv" % datetime.datetime.utcfromtimestamp(time.time()).isoformat())
filepath = path + log_name
log_file = open(filepath, "w")
print ("Using logfile %s\n" % filepath)

log_file.write("log_index;system_timestamp;diff_press[Pa];mag_x;mag_y;mag_z;mag_hdg[deg];spd_from_dp[m/s];temp[degC];gps_timestamp;gps_hdg[deg];gps_sogk[m/s];p_altimet[Pa];temp_altimet[degC];temp_sht[degC];hum_sht[Percent]\n")

#### Measurement ###################################################
log_index = 0
meas_freq = 10; #rough frequency of diff. pressure measurement (gps data frequency is 1 Hz)
gps_raw = ""
first = True

while True:

    try:

        if serialPort is not None:


            if first:
                while gps_raw.find('VTG') < 0 :
                    gps_raw = serialPort.readline()
                    if (gps_raw.find('VTG') > 0):
                        break

            if (serialPort.inWaiting()>0 and not first): #if incoming bytes are waiting to be read from the serial input buffer
                gps_raw = serialPort.readline(serialPort.inWaiting())


            first = False

            if gps_raw.find('VTG') > 0:
                gps_parsed = pynmea2.parse(gps_raw)
                gps_tt = gps_parsed.true_track
                gps_sogk = gps_parsed.spd_over_grnd_kmph
                gps_parsed = pynmea2.parse(serialPort.readline())
                gps_ts = gps_parsed.timestamp

        if error == True:
            windgauge.route()
            windgauge.reset()
            windgauge.initialize()
            error = False

        time.sleep(0.01)
        # print(windgauge.read_icm20948_reg_data(windgauge.ICM20948_EXT_SLV_SENS_DATA_00, 0, 18)) # reading data from EXT_SLV_SENS_DATA_00 register
        #                                                                             # (9 bytes from SDP3X and 9 bytes from magnetometer)

        # acc_x, acc_y, acc_z = windgauge.get_accel()
        # sys.stdout.write("%8.2f; %8.2f; %8.2f              " % (acc_x, acc_y, acc_z ))

        # sys.stdout.write("%6.2f; %6.2f; %6.2f            " % windgauge.get_gyro())

        # sys.stdout.write("%8.2f; %8.2f; %8.2f;           " % windgauge.get_mag())

        mag_hdg_comp = windgauge.get_mag_hdg()
        new_hdg = mag_hdg_comp
        mag_x, mag_y, mag_z = windgauge.get_mag_raw()
        hdg_ma, hdg_vect, prev_hdg_ma = heading_ma(new_hdg, hdg_vect, ma_len, prev_hdg_ma)

        dp, spd_from_dp = windgauge.get_dp_spd()
        temp = windgauge.get_t()
        (altimet_t1, altimet_p1) = altimet.get_tp()

        temperature, humidity = sht.get_TempHum()

        ts = datetime.datetime.utcfromtimestamp(time.time()).isoformat()

        # print ("Heading: %6.2f [deg]; Diff. P: %7.2f [Pa]; Speed from diff. P: %5.2f [km/h]" % (hdg_ma, dp, spd_from_dp))
        if serialPort is not None:
            if(gps_ts is None):
                gps_ts = ""
            if(gps_sogk is None):
                gps_sogk = ""
            if(gps_tt is None):
                gps_tt = ""
            msg = ("%d;%s;%0.2f;%0.2f;%0.2f;%0.2f;%0.2f;%0.2f;%0.3f;%s;%s;%s\n"% (log_index, ts, dp, mag_x, mag_y, mag_z, hdg_ma, spd_from_dp, temp, gps_ts, gps_tt, gps_sogk))
            #print(msg)
            log_file.write(msg)
            sys.stdout.write("%s; %s; Dp: %+4.2f [Pa]; T: %2.3f [degC];" % (str(log_index).zfill(4), ts, dp, temp))
            sys.stdout.write(" GPS_TS: %s; GPS_HDG: %s [deg]; GPS_SOG: %s [km/h]\n" % (gps_ts, gps_tt, gps_sogk))
            sys.stdout.write(" MAG_X: %+4.2f;MAG_Y: %+4.2f;MAG_Z: %+4.2f;MAG_HDG: %+4.2f; SPD_W_DP: %+4.2f [km/h]\n" % (mag_x, mag_y, mag_z, hdg_ma, spd_from_dp))
            sys.stdout.flush()
        else:
            msg = ("%d;%s;%0.2f;%0.2f;%0.2f;%0.2f;%0.2f;%0.2f;%0.3f;;;;%0.3f;%0.3f;%0.3f;%0.3f\n"% (log_index, ts, dp, mag_x, mag_y, mag_z, hdg_ma, spd_from_dp, temp, altimet_p1, altimet_t1,temperature, humidity))
            sys.stdout.write("%s; %s; Dp: %+4.2f [Pa]; T: %2.3f [degC]; " % (str(log_index).zfill(4), ts, dp, temp))
            sys.stdout.write("P: %+4.2f [Pa]; T: %2.3f [degC]; " % (altimet_p1, altimet_t1))
            sys.stdout.write("Temp:  %2.3f [degC]; Hum: %2.3f [Percent]; " % (temperature, humidity))
            sys.stdout.write("MAG_X: %+4.2f;MAG_Y: %+4.2f;MAG_Z: %+4.2f;MAG_HDG: %+4.2f; SPD_W_DP: %+4.2f [km/h]\n" % (mag_x, mag_y, mag_z, hdg_ma, spd_from_dp))
            sys.stdout.flush()
            log_file.write(msg)

        log_index += 1

    except KeyboardInterrupt:
        windgauge.stop()
        print("\nMeasurement stopped!\n")
        log_file.close()
        sys.exit(0)

    except IOError:

        sys.stdout.write("\r\n************ I2C Error\r\n\n")
        time.sleep(0.1)
        error = True

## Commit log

2019-01-23 Copy of code from WINDGAUGE01A before creation of new version design begins.
    [P_WINDGAUGE01A_D01.scad, P_WINDGAUGE01A_D02.scad, P_WINDGAUGE01A_R01.scad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]
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2019-02-06 Doplneni grid-fins podle: https://github.com/UniversalScientificTechnologies/AutomaticWeatherStation/issues/1
    [venturi_tube.scad, venturi_tube.stl]
2019-02-07 Pokračování tvorby modelu. Vytvoření tvarového přídavku pro umístění elektroniky. Z issue: https://github.com/UniversalScientificTechnologies/AutomaticWeatherStation/issues/1
    [WINDGAUGE_D01.scad, WINDGAUGE_D02.scad, WINDGAUGE_R01.scad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]
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2019-03-01 Přidání ochranného lemu a testovacího prostupu pro ložisko.
    [venturi_tube.scad, venturi_tube.stl]
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2019-04-03 Updated WindGauge 3A with opening PCB casing, cabling pipeline and Venturi tube windpipes.
    [venturi_tube.scad]
2019-04-04 Fixed WindGauge 3A cabling pipeline and Venturi tube windpipes.
    [venturi_tube.scad]
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2019-04-04 Reworked broken WindGauge 3A cabling pipeline and Venturi tube windpipes.
    [venturi_tube.scad]
2019-04-04 Commented out prototyping cut-out cube from WindGauge 3A.
    [venturi_tube.scad]
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2019-04-09 Editing printig models and files Creating makefile Render printing files
    [P_WINDGAUGE01A_D02.stl, P_WINDGAUGE01A_R01.stl, P_WINDGAUGE01A_R03.stl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]
2019-04-12 Venturi tube height can be changed by parameter V_h in WindGauge 3A.
    [WINDGAUGE_R03.scad]
2019-04-13 WINDGAUGE03A - Renamed parameters to be more readable. Added parameter global_clearance for fine printer settings. Pressure tubes replaced to vertical position + added parameters R03_sensor_offset an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
    [WINDGAUGE_R03.scad, WINDGAUGE_R04.scad, configuration.scad]
2019-04-22 WINDGAUGE03A - Updated PCB casing to ease printing. KNOWN ISSUE - Drop shape lid does not cut-out triangular prism. Lid will not fit on model.
    [WINDGAUGE_R03.scad, WINDGAUGE_R04.scad, configuration.scad]
2019-04-23 Fixed polyhedrons and cabling intake.
    [WINDGAUGE_R03.scad]
2019-04-23 WINDGAUGE03A - fixed drop shape TOP cut-out (commented instead of prototyping cut-out cube by mistake).
    [WINDGAUGE_R03.scad]
2019-04-23 WINDGAUGE03A - Added parameter R03_sealing_ring_thickness to account for sealing rings in airtubes.
    [WINDGAUGE_R03.scad, configuration.scad]
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2019-04-24 Fix poor resolution of PCB cover.
    [P_WINDGAUGE03A_R04.scad, P_WINDGAUGE03A_R04.stl]
2019-04-25 WINDGAUGE03A #10 - Printing tolerance is now added only in the lid cut-out, not on tube platform. Lid cut-out cube size doubled.
    [WINDGAUGE_R03.scad, WINDGAUGE_R04.scad, configuration.scad]
2019-04-28 WINDGAUGE03A #13 - Replaced screw holes with bolt holes and nut pockets.
    [P_WINDGAUGE03A_R03.stl, P_WINDGAUGE03A_R04.stl, WINDGAUGE_R03.scad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]
2019-04-28 WINDGAUGE03A #11 - Cabling hole curves are less steep now.
    [P_WINDGAUGE03A_R03.stl, WINDGAUGE_R03.scad, WINDGAUGE_R03.stl]
2019-04-30 WINDGAUGE03A #12 - Small fix for parameter R03_slip_ring_offset to work. Do not exceed [-20:20] or cabling hole will penetrate the tube body.
    [WINDGAUGE_R03.scad, configuration.scad]
2019-04-30 WINDGAUGE03A #13 - Fixed forgotten R03_inner_screw_diameter. Added R03_global_clearance around nuts and bolts.
    [P_WINDGAUGE03A_R03.stl, P_WINDGAUGE03A_R04.stl, WINDGAUGE_R03.scad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]
2019-05-01 WINDGAUGE03A #14 - Updated sensor holes to fit sealing rings properly.
    [WINDGAUGE_R03.scad]
2019-05-01 WINDGAUGE03A #13 - Removed R03_global_clearance around nuts and bolts.
    [P_WINDGAUGE03A_R03.stl, P_WINDGAUGE03A_R04.stl, WINDGAUGE_R03.scad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]
2019-05-01 WINDGAUGE03A #14 - Changed R03_sealing_ring_thickness parameter to 1.5mm.
    [P_WINDGAUGE03A_R03.stl, WINDGAUGE_R03.stl, configuration.scad]
2019-05-02 WINDGAUGE03A #15 - Updated venturi tube with fin holders and cut-out. Fixed parameter name R01_vyska_prekryti_statoru in WINDGAUGE_S01.scad.P_WINDGAUGE03A_R03.stl
    [WINDGAUGE_R03.scad, WINDGAUGE_S01.scad, configuration.scad]
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2019-05-03 WINDGAUGE03A #15 - Created sources and stl with venturi tube fin.
    [P_WINDGAUGE03A_R05.scad, P_WINDGAUGE03A_R05.stl, WINDGAUGE_R05.scad]
2019-05-03 WINDGAUGE03A #12 - Added cut-out for balance weights. Size can be adjusted by changing parameters R03_balance_shelf_width and R03_balance_shelf_height (depth is set to max - not configurable).
    [WINDGAUGE_R03.scad, configuration.scad]
2019-05-05 WINDGAUGE03A #11 - Top part of cabeling hole widened.
    [WINDGAUGE_R03.scad]
2019-05-05 WINDGAUGE03A #10 - Moved PCB cut-out ceiling upwards 0.75 to compensate for printer inaccuracy.
    [P_WINDGAUGE03A_R04.stl, WINDGAUGE_R03.scad]
2019-05-05 WINDGAUGE03A #10 - Changed fixed 0.75mm vertical separation for 1.5xR03_global_clearance.
    [WINDGAUGE_R03.scad]
2019-05-05 WINDGAUGE03A #16 - A little house-cleaning -> no change in model (hopefully :-) ).
    [WINDGAUGE_D02.scad]
2019-05-05 WINDGAUGE03A #16 - Added holes and nut pockets for magnets. Middle base nut pocket moved to the opposite side of base. Renamed configuration parameters (mostly translated to english).
    [P_WINDGAUGE03A_D02.scad, P_WINDGAUGE03A_D02.stl, WINDGAUGE_D02.scad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]
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2019-05-06 WINDGAUGE03A #15 - Fixed bolt holes distance.
    [P_WINDGAUGE03A_R05.stl, WINDGAUGE_R05.scad]
2019-05-06 WINDGAUGE03A #15 - Fixed holder width to fit 12mm bolt.
    [configuration.scad]
2019-05-07 WINDGAUGE03A #16 - Added global_clearance to magnet base diameter. Added thin layer over magnet bolt hole to improve printing. Moved magnet holes closer to the edge of base.
    [P_WINDGAUGE03A_D02.stl, WINDGAUGE_D02.scad, configuration.scad]
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2019-05-11 WINDGAUGE03A #16 - Added draft parametr into the model. If draft = true, model is™ in original position with reduced resolution to achieve short rendering time. If draft = false, model is moved to pr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
    [WINDGAUGE_D02.scad]
2019-05-15 WINDGAUGE03A #18 - Updated Makefile to check dependencies, compile only print versions of models and create PNG images from STL files instead of rendering them again. Created new folder with models d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
    [P_WINDGAUGE03A_D02.scad, P_WINDGAUGE03A_D02.stl, P_WINDGAUGE03A_R01.scad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]
2019-05-16 WINDGAUGE03A #18 - Dependency files are now sorted to avoid false git changes.
    [WINDGAUGE_R03.stl]
2019-06-13 WINDGAUGE03A #11 - Created cut-out for extra cabling. Changed moreShapes.scad library module torusSlice to use difference instead of intersection for improved performance.
    [WINDGAUGE_R03.scad, WINDGAUGE_R03.stl]
2019-06-13 WINDGAUGE03A #11 - Reverted prototyping changes forgotten in last commit.
    [WINDGAUGE_R03.scad, WINDGAUGE_R03.stl]
2019-09-04 WINDGAUGE03A #21 - Fixed nut/bolt holes for fin holder in non-draft mode.
    [WINDGAUGE_R03.scad, WINDGAUGE_R03.stl]
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2020-01-22 Přegenerování souborů novou verzí OpenSCADu Problém s STL S01 vyřešen ručním vygenerováním AMF.
    [WINDGAUGE_D01.stl, WINDGAUGE_D02.stl, WINDGAUGE_R01.stl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]
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2020-02-11 FIX hole in front of PCB covering drop. start to shift the covering drop from the front of the venturi tube.
    [WINDGAUGE_R03.scad, configuration.scad]
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2020-02-20 Improving the magnetic variant base stability.
    [WINDGAUGE_D02.scad, configuration.scad]
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2020-03-11 Odebrání kapsy pro kabely Odstranění chybně oříznutého výstupku pro PCB Zvětšení průměru nejužší části anemometru.
    [WINDGAUGE_D02.stl, WINDGAUGE_R03.scad, WINDGAUGE_R03.stl]
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2020-03-23 #WINDGAUGE03A #28 - Changed direction of viring tube connection from the bottom to the side.
    [WINDGAUGE_R03.scad, WINDGAUGE_R03.stl]
2020-03-25 WINDGAUGE03A #29 - Enlarged space between PCB platform and drop cover for viring.
    [WINDGAUGE_R03.scad, WINDGAUGE_R04.stl]
2020-03-26 #WINDGAUGE03A #30 - Increased gap between S01 and R03 parts by 0,4mm. Gap is now 1mm (2*R03_global_clearance) instead of 0,6mm (0,5*S01_sila_materialu)
    [WINDGAUGE_R03.scad]
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2020-04-07 #WINDGAUGE03A #12 - Changes to balance rotational parts R03, R04 and R05.
    [BOLT_M3x12.amf, BOLT_M3x12.scad, BOLT_M3x12.stl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]
2020-04-15 #WINDGAUGE03 #1 - Reduced diameter of venturi tube narrow part. For printing, use amf/gcode/WINDGAUGE_R03_mod.gcode = WINDGAUGE_R03 with balance modifiers.
    [WINDGAUGE_R03.amf, WINDGAUGE_R03.scad, WINDGAUGE_R03_mod.amf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]
2020-04-16 #WINDGAUGE03A #12 Fixed wront indentation
    [assembly.scad]
2020-04-16 MLAB-project/Modules#12 Updated Makefile to create AMF + STL + PNG as default. Created merge_modifiers.sh function to merge modifiers into their base AMF file (called in make automatically). KNOWN BU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
2020-05-18 Improve Z modificator efficiency https://github.com/MLAB-project/Modules/issues/12.
    [WINDGAUGE_R03.scad]
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2020-05-22 MLAB-project/Modules#12 Changed curvedPipe library to make tube segments overlap (avoiding problems with model not being valid 2-manifold).
2020-05-22 MLAB-project/Modules#12 Fixed problems with model consistency and wall protrusions.
    [WINDGAUGE_R03.scad, WINDGAUGE_R03_mod.amf]
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2020-05-22 MLAB-project/Modules#12 Changed link to R03 in assembly from AMF to STL (amf now contains modifier).
    [assembly.scad]
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2020-05-22 MLAB-project/Modules#12 Changed venturi tube wall thickness from 3 to 5mm to fit tube cut-outs.
    [configuration.scad]
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2020-06-08 mlab-modules/WINDGAUGE03#3 mlab-modules/WINDGAUGE03#4 mlab-modules/WINDGAUGE03#5 mlab-modules/WINDGAUGE03#6 Reverted R04 space for cables and rounded edges. Smoothed-out cable in and out. Tightened s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
    [BOLT_M3x12.amf, BOLT_M3x12.scad, BOLT_M3x12.stl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]
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2020-06-17 mlab-modules/WINDGAUGE03#9 Added holes for M3x12 bolt/nut to tighten slip-ring in R03.
    [WINDGAUGE_R03.scad]
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2020-11-13 Modify slip ring mount to fit Adafruit Slip Ring Flange 22mm P736 http://adafru.it/736
    [WINDGAUGE_R04.amf, WINDGAUGE_S01.amf, WINDGAUGE_S01.scad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]
2020-11-16 Add a plain copy of pymlab windgaue03 example. The script should be modified to record raw data.
    It is related to calibration verification from issue #15.
    [serial_logger.py]
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2020-11-18 Oprava dle issue #11
    [WINDGAUGE_S04_USBI2C01A.scad]
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
